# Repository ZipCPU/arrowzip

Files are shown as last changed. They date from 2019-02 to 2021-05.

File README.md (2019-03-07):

## ArrowZip

This design is currently a work in progress.  The goal is to place a
[ZipCPU](http://zipcpu.com/about/zipcpu.html) onto a
[$30 Max1000 FPGA](http://zipcpu.com/blog/2017/12/16/max1k.html),
as sold by [Arrow](https://www.arrow.com) and
[Trenz Electronics](https://www.trenz-electronic.de).

If all goes well, this will include access to ...

- The on-board SDRAM.  This includes not only the
  [Verilog code](rtl/arrowzip/wbsdram.v) to access this SDRAM, but also a
  [simulation component](sim/verilated/sdramsim.cpp) for the SDRAM, as well
  as an [AutoFPGA](https://github.com/ZipCPU/autofpga)
  [script](auto-data/sdram.txt)
  to add (or remove) the SDRAM from this build.

  This capability now works.

- A dual-I/O flash, running in both XIP (Execute in Place) mode as well as
  a debug-bus configuration override.  As with the SDRAM, this will include
  not only the [Verilog code](rtl/arrowzip/dualflexpress.v), but also a
  simulation component and an [AutoFPGA](https://github.com/ZipCPU/autofpga)
  [script](auto-data/flexpress.txt)
  to add (or remove) the flash from this build.

  The [flash controller](rtl/arrowzip/dualflexpress.v) now works as well.

- The on-board MEMS motion sensor.

  This last piece remains a work in progress.

## 20190307 Update: The SDRAM is working

1. The design now builds and runs, both in simulation and on hardware, using
   the [flash controller](rtl/arrowzip/dualflexpress.v).

2. The [SDRAM controller](rtl/arrowzip/wbsdram.v) now passes a [memory
   test](sw/board/memtest.c), and should be ready to use.

3. The I/O drivers are currently Intel generated IP.  These still need to
   be replaced by references to the actual underlying drivers.  However, if you
   create the I/O drivers yourself, then you can run the design as is.

## To run this design ...

First, install Quartus, Verilator, and the
[ZipCPU toolchain](https://zipcpu.com/zipcpu/2018/01/31/cpu-build.html).

To run from simulation, build the design (make) and then cd into
the [sim/verilated](sim/verilated/).  Type "main_tb" to start the simulator.
"main_tb -d" will start creating a VCD file at the same time.  "main ../../sw/board/cputest" will load the CPU test into the [ZipCPU](https://zipcpu.com/about/zipcpu.html).  While running the simulation, you can telnet into "localhost 6956" to interact with the serial port of the design.  You can also use the [wbregs program](sw/host/wbregs.cpp) to read and set various addresses peripheral and otehrwise within the design.

For example, "wbregs stopwatch 1" will start the stopwatch capability. "wbregs timer 0x130" will start a timer counting down from one minute and thirty seconds.  "wbregs clock 0x210837" will set the RTC clock time to 9:08:37 PM.

To run the design on the device itself, build the design and then load it into
the device (see the vendor's instructions) and then run "netuart" from the
[sw/host](sw/host) directory.  You may need to give it the name of your serial
port, as in "netuart /dev/ttyUSB0".  (Both the simulator and [netuart](sw/host/netuart.cpp) use the same network port, so you'll only be able to run one of these at a time.)  You should then be able to use the [wbregs](sw/host/wbregs.cpp) program to interact with the various registers within the design.  To load the [cputest](sw/board/cputest.c), run "[zipload](sw/host/zipload.c) -r [../board/cputest](sw/board/cputest.c)" from the [sw/host](sw/host) directory.  You should then see a series of tests results posted on the serial port.

To reconfigure the design, such as to add or remove device or to adjust the amount of block RAM, you'll need to adjust the files in the [auto-data](auto-data) directory and re-run [AutoFPGA](https://github.com/ZipCPU/autofpga).

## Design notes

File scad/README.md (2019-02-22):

## SCAD Drawings

This directory contains such SCAD drawings as can be used to create a case
using [OpenSCAD](http://www.openscad.org).  There's also an [STL](arrowzip.stl)
file, also generated by [OpenSCAD](http://www.openscad.org), that you can use
with your printer if you don't want to generate it yourself using
[OpenSCAD](http://www.openscad.org).

Use them at your own risk, as my first version tore the buttons off of the side
of my board.

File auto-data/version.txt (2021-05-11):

################################################################################
##
## Filename: 	version.txt
## {{{
## Project:	ArrowZip, a demonstration of the Arrow MAX1000 FPGA board
##
## Purpose:	
##
## Creator:	Dan Gisselquist, Ph.D.
##		Gisselquist Technology, LLC
##
################################################################################
## }}}
## Copyright (C) 2017-2021, Gisselquist Technology, LLC
## {{{
## This program is free software (firmware): you can redistribute it and/or
## modify it under the terms of  the GNU General Public License as published
## by the Free Software Foundation, either version 3 of the License, or (at
## your option) any later version.
##
## This program is distributed in the hope that it will be useful, but WITHOUT
## ANY WARRANTY; without even the implied warranty of MERCHANTIBILITY or
## FITNESS FOR A PARTICULAR PURPOSE.  See the GNU General Public License
## for more details.
##
## You should have received a copy of the GNU General Public License along
## with this program.  (It's in the $(ROOT)/doc directory.  Run make with no
## target there if the PDF file isn't present.)  If not, see
## <http://www.gnu.org/licenses/> for a copy.
## }}}
## License:	GPL, v3, as defined and found on www.gnu.org,
## {{{
##		http://www.gnu.org/licenses/gpl.html
##
################################################################################
##
## }}}
@PREFIX=version
@DEVID=VERSION
@NADDR=1
@SLAVE.TYPE=SINGLE
@SLAVE.BUS=wb
@MAIN.DEFNS=
`include "builddate.v"
@MAIN.INSERT=
	assign	@$(PREFIX)_data = `DATESTAMP;
	assign	@$(PREFIX)_ack = wb_stb && @$(PREFIX)_sel;
	assign	@$(PREFIX)_stall = 1'b0;
@REGS.N=1
@REGS.0= 0 R_@$(DEVID) @$(DEVID)
@BDEF.IONAME=_@$(PREFIX)
@BDEF.IOTYPE=unsigned
@BDEF.OSDEF=_BOARD_HAS_@$(DEVID)
@BDEF.IOTYPE=static volatile @$BDEF.IOTYPE *const @$BDEF.IONAME = &((@$BDEF.IOTYPE *)@$[0x%08x](REGBASE));
##
##
##
@PREFIX=buildtime
@DEVID=BUILDTIME
@NADDR=1
@SLAVE.TYPE=SINGLE
@SLAVE.BUS=wb
@MAIN.DEFNS=
// BUILDTIME doesnt need to include builddate.v a second time
// `include "builddate.v"
@MAIN.INSERT=
`ifdef	VERILATOR
	assign	@$(PREFIX)_data = `BUILDTIME ^ 32'h8000_0000;
`else
	assign	@$(PREFIX)_data = `BUILDTIME;
`endif
	assign	@$(PREFIX)_ack = wb_stb && @$(PREFIX)_sel;
	assign	@$(PREFIX)_stall = 1'b0;
@REGS.N=1
@REGS.0= 0 R_@$(DEVID) @$(DEVID)
@BDEF.IONAME=_@$(PREFIX)
@BDEF.IOTYPE=unsigned
@BDEF.OSDEF=_BOARD_HAS_@$(DEVID)
@BDEF.IOTYPE=static volatile @$BDEF.IOTYPE *const @$BDEF.IONAME = &((@$.BDEF.IOTYPE *)@$[0x%08x](REGBASE));

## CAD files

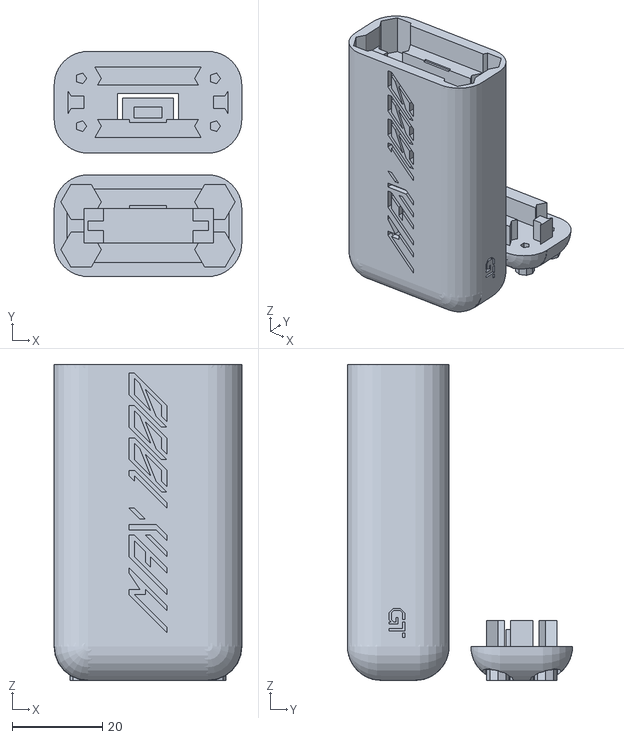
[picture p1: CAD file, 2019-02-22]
scad/arrowzip.stl
41.7 x 50.0 x 70.2

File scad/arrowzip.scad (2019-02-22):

include <GT.scad>
include <zipcpu.scad>
include <max1klogo.scad>
	
module	arrowcase(cap = 0) {
	//
	// Measurements
	raw_board_thickness =  1.3;
	bx_component_thickness = 2*(3.2-raw_board_thickness)
					+raw_board_thickness + 2.5;
	raw_board_width     = 26.0;
	raw_board_length    = 62.0;
	//
	bx_board_thickness     = raw_board_thickness + 0.7;
	bx_board_width         = raw_board_width  + 0.7;
	bx_board_length        = raw_board_length + 0.7;
	bx_clear_board_edge    =  7.0;
	//
	usb_height = 4.2-raw_board_thickness + 0.5;
	usb_width  = 7.6  + 0.5;
	usb_depth  = 5.25 + 0.5;

	////////////////////////////
	//
	// USB plug dimensions
	//
	// This isn't the actual metal USB size.  That's fixed by the
	// standard.  This is the size of the plastic that surrounds
	// that plug.
	//
	// First USB plug dimensions
	// usb_plug_width = 10.1 + 1.5;
	usb_plug_height=  6.8 + 1.5;

	// Second plug dimensions
	usb_plug_width = 11.8 + 1.5;
	// usb_plug_height=  5.9 + 1.5;

	// Second plug dimensions
	// usb_plug_width = 9.0 + 1.5;
	usb_plug_height=  7.6 + 1.5;

	////////////
	//
	standoff_height       = 10;
	standoff_flat_to_flat = 4.5;
	//
	screw_diameter= 2.5;
	screw_length  = 4.1;
	screw_head_diameter = 5.5+0.6;
	screw_head_height   = 1.5;
	//
	// Derived measurements
	// standoff_radius = standoff_flat_to_flat / sqrt(2.0);
	// Because this is an "inside" standoff, it the radius is measured
	// to the flats, not the corners
	standoff_radius = standoff_flat_to_flat;
	//
	// My choices
	tolerance = 0.1;
	bx_edge_thickness = standoff_flat_to_flat + 3;
	bx_component_width = bx_board_width-bx_clear_board_edge;
	chamber_height = bx_component_thickness;
	exwidth  = bx_board_width    + 2*bx_edge_thickness;
	exlength = bx_board_length   + 2*bx_edge_thickness;
	exheight = chamber_height    + 2*bx_edge_thickness;
	
	inx = bx_edge_thickness + tolerance/2;
	iny = bx_edge_thickness + tolerance/2;
	inz = bx_edge_thickness;
	bottom_of_board = inz + chamber_height/2-bx_board_thickness/2;
	
	module raw_case() {
		cube([exwidth, exlength, exheight]);
	}
	
	module	rounded_case() {
		rad = bx_edge_thickness;
		tol = tolerance;
		union() {
			difference() {
				raw_case();
				//
				translate([-tol,-tol,-tol])
					cube([rad+tolerance,exlength+2*tol,
						rad+tol]);
				translate([exwidth-rad,-tolerance,-tolerance])
					cube([rad+tol,exlength+2*tol,
						rad+tol]);
				translate([-tolerance,exlength-rad,-tol])
					cube([exwidth+2*tol,rad+tol,
						rad+tol]);
				translate([-tol,exlength-rad,-tol])
					cube([rad+tol,rad+tol,
						exheight+2*tol]);
				translate([exwidth-rad,exlength-rad,-tol])
					cube([rad+tol,rad+tol,
						exheight+2*tol]);
				// Top side
				translate([-tol,-tol,exheight-rad])
					cube([rad+tol,exlength+2*tol,
						rad+2*tol]);
				translate([exwidth-rad,-tol,exheight-rad])
					cube([rad+tol,exlength+2*tol,
						rad+2*tol]);
				translate([-tol,exlength-rad,exheight-rad])
					cube([exwidth+2*tol,rad+2*tol,
						rad+2*tol]);
				// Front side
				translate([-tol,-tol,-tol])
					cube([exwidth+2*tol,rad+tol,
						rad+tol]);
				translate([-tol,-tol,exheight-rad])
					cube([exwidth+2*tol,rad+tol,
						rad+tol]);
				translate([-tol,-tol,-tol])
					cube([rad+tol,rad+tol,
						exheight+2*tol]);
				translate([exwidth-rad,-tol,-tol])
					cube([rad+tol,rad+tol,
						exheight+2*tol]);
			}
	
			// The corners
			translate([rad,exlength-rad,rad])
				sphere(rad);
			translate([exwidth-rad,exlength-rad,rad])
				sphere(rad);
			translate([rad,exlength-rad,exheight-rad])
				sphere(rad);
			translate([exwidth-rad,exlength-rad,exheight-rad])
				sphere(rad);
			// Front corners
			translate([rad,rad,rad])
				sphere(rad);
			translate([exwidth-rad,rad,rad])
				sphere(rad);
			translate([rad,rad,exheight-rad])
				sphere(rad);
			translate([exwidth-rad,rad,exheight-rad])
				sphere(rad);
	
	
	
			// The sides
			translate([rad,rad,rad]) rotate([-90,0,0])
				cylinder(h=exlength-2*rad,r=rad);
			translate([exwidth-rad,rad,rad]) rotate([-90,0,0])
				cylinder(h=exlength-2*rad,r=rad);
			translate([rad,exlength-rad,rad]) rotate([0,90,0])
				cylinder(h=exwidth-2*rad,r=rad);
			// And on the top
			translate([rad,rad,exheight-rad]) rotate([-90,0,0])
				cylinder(h=exlength-2*rad,r=rad);
			translate([exwidth-rad,rad,exheight-rad]) rotate([-90,0,0])
				cylinder(h=exlength-2*rad,r=rad);
			translate([rad,exlength-rad,exheight-rad]) rotate([0,90,0])
				cylinder(h=exwidth-2*rad,r=rad);
			// Vertical supports
			translate([rad,exlength-rad,rad])
				cylinder(h=exheight-2*rad,r=rad);
			translate([exwidth-rad,exlength-rad,rad])
				cylinder(h=exheight-2*rad,r=rad);
			// The front face
			translate([rad,rad,rad]) rotate([0,90,0])
				cylinder(h=exwidth-2*rad,r=rad);
			translate([rad,rad,exheight-rad]) rotate([0,90,0])
				cylinder(h=exwidth-2*rad,r=rad);
			translate([exwidth-rad,rad,rad])
				cylinder(h=exheight-2*rad,r=rad);
			translate([rad,rad,rad])
				cylinder(h=exheight-2*rad,r=rad);
		}
	}
	
	module	inside_chamber() {
		bw = bx_board_width;
		ch = chamber_height;
		cw = bx_component_width;
		// tol=tolerance;
		tol=0.1;
		spare_end_width = 22;
		btnw = 1;

		union() {
			// Room for the bare board
			//
			translate([inx-tol/2, iny-tol/2,
					inz+(ch-bx_board_thickness-tol)/2])
				cube([bx_board_width+tol,
					bx_board_length+tol,
					bx_board_thickness+tol]);
	
			// Room for the electronics around the board
			translate([inx+(bw-cw-tol)/2, iny-tol/2+bx_clear_board_edge/2,
					inz-tol/2])
				cube([cw + tol,
					bx_board_length-bx_clear_board_edge/2+tol,
					chamber_height+tol]);

			// Room for the electronics near the end
			translate([inx-btnw+tol/2, iny-tol/2,
					inz-tol/2])
				cube([bx_board_width+btnw*2+tol,
					spare_end_width+tol,
					chamber_height+tol]);
		}
	}
	
	module	board() {
		color("green") {
			translate([inx, iny,
				bottom_of_board])
				cube([bx_board_width, bx_board_length, bx_board_thickness]);
		}
	}
	
	module	embossGT() {
		s = 0.25;
		depth = 1.5;
		union() {
			translate([exwidth+gtlogo_h*s/2-depth,
				exlength-2*s*gtlogo_l-bx_edge_thickness-1.5,
				gtlogo_l*s/2+bx_edge_thickness]) {
			rotate([0,0,90]) { rotate([90,0,0]) { scale([s,s,s]) {
				translate([-gtlogo_w*s,-gtlogo_l*s,-gtlogo_h*s]);
						GTlogo(); }
			}}}
	
			translate([-gtlogo_h*s/2+depth,
				gtlogo_l*s+bx_edge_thickness + 3,
				gtlogo_w*s/2+bx_edge_thickness]) {
			rotate([0,0,-90]) { rotate([90,0,0]) { scale([s,s,s]) {
	
				translate([-gtlogo_w*s,-gtlogo_l*s,-gtlogo_h*s])
					GTlogo(); }
			}}}
		}
	}
	
	module	embossZip() {
		s = 1.0;
		depth = 1.5;
		union() {
			translate([exwidth/2,
				exlength/2,
				exheight+zlogoh/2-depth])
			{
			rotate([0,0,90]) scale([s,s,1]) {
				translate([-zlogow/2,(zlogob-zlogol)/2,-zlogoh/2])
						zipcpulogo(); }
			}
		}
	}

	module	embossMax1k(depth) {
		s = 1.2;
		sw = s * max1klogo_w;
		sl = s * max1klogo_l;
		sh = max1klogo_l;
		depth = 1.5;
		union() {
			translate([exwidth/2,
				exlength/2,
				-max1klogo_h/2+depth])
			{
			rotate([0,180,90]) scale([s,s,1]) {
				translate([-max1klogo_w/2,-max1klogo_l/2,-max1klogo_h/2])
						max1klogo(); }
			}
		}
	}

	module	standoff_holes() {
		tol = tolerance;
		rad = standoff_flat_to_flat;
		shp = standoff_height+tol;
		// Inset = (distance from edge) + rad/2
		// Inset = 2mm + rad
		inset = 1.5+rad;
		translate([inset, iny+standoff_height+tol, inset])
			rotate([90,0,0])
				cylinder(h=shp,r=standoff_radius,$fn=6);
		translate([exwidth-inset, iny+standoff_height+tol, inset])
			rotate([90,0,0])
				cylinder(h=shp,r=standoff_radius,$fn=6);
		translate([inset, iny+standoff_height+tol, exheight-inset])
			rotate([90,0,0])
				cylinder(h=shp,r=standoff_radius,$fn=6);
		translate([exwidth-inset, iny+standoff_height+tol,	
				 exheight-inset])
			rotate([90,0,0])
				cylinder(h=shp,r=standoff_radius,$fn=6);
	
		// clean things up a ... touch
		/*
		translate([rad, iny-tol, rad*3/4])
			cube([exwidth-2*rad,standoff_height+tol,
				exheight-2*rad*3/4]);
		*/
		/*
		translate([rad, iny-tol, rad])
			cube([exwidth-2*rad,standoff_height+tol,
				exheight-rad*2.0]);
		*/
	}
	
	module	screw_holes() {
		tol = tolerance;
		rad = standoff_flat_to_flat;
		inset = 1.5+rad;
		srad= (screw_diameter)/2;
		sch= iny+standoff_height/2;
		headr = (screw_head_diameter+0.8+tol)/2;
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

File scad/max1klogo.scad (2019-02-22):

module	max1klogo() {
	module	max1k() {
		linear_extrude(height=5) {
			union() {
				// M
				polygon(points=[
					[0,0],
					[1,0],
					[7,6],
					[7,4],
					[8,4],
					[4,0],
					[5,0],
					[12,7],
					[11,7],
					[8,5],
					[8,7],
					[7,7] ]);
				// A
				polygon(points=[
					[7,0],
					[8,0],
					[14,6],
					[17,6],
					[15,4],
					[13,4],
					[12,3],
					[14,3],
					[11,0],
					[12,0],
					[18,6],
					[18,7],
					[14,7],
					]);
				// X
				polygon(points=[
					[14,0],
					[15,0],
					[18,3],
					[18,4] ]);
				polygon(points=[
					[17,0],
					[18,0],
					[20,2],
					[20,7],
					[19,7],
					[19,2] ]);
				polygon(points=[
					[21,4],
					[23,6],
					[23,7],
					[21,5],
					 ]);
			}
		}
	}

	module	max1k1k() {
		linear_extrude(height=5) {
			union() {
				// 1
				polygon(points=[
					[0,0],
					[1,0],
					[7,6],
					[7,7],
					[6,7],
					[5,6],
					[6,6] ]);
				// 0
				translate([0,0,0]) { polygon(points=[
					[3,1],
					[3,0],
					[9,6],
					[12,6],
					[11,5],
					[6,3],
					[5,2],
					[10,4],
					[7,1],
					[5,1],
					[4,0],
					[7,0],
					[13,6],
					[13,7],
					[9,7],
					]); }
				// 0
				translate([6,0,0]) { polygon(points=[
					[3,1], [3,0], [9,6], [12,6], [11,5],
					[6,3], [5,2], [10,4], [7,1], [5,1],
					[4,0], [7,0], [13,6], [13,7], [9,7]
					]); }
				// 0
				translate([12,0,0]) { polygon(points=[
					[3,1], [3,0], [9,6], [12,6], [11,5],
					[6,3], [5,2], [10,4], [7,1], [5,1],
					[4,0], [7,0], [13,6], [13,7], [9,7]
					]); }
			}
		}
	}

	translate([0,0,0]) {
		max1k();

		translate([23,0,0]) {
			max1k1k();
		}
	}
}

max1klogo_w = 47;
max1klogo_l = 7;
max1klogo_h = 5;

module	max1kshell() {
	difference() {
		w = 2;
		translate([-w/2,-w/2,-w+0.2]) {
			cube([max1klogo_w+w, max1klogo_l+w, max1klogo_h]);
		}
		cube([max1klogo_w, max1klogo_l, max1klogo_h]);
	}
}

// max1kshell();
// max1klogo();

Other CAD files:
scad/GT.scad
scad/zipcpu.scad

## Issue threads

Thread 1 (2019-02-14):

great project

NeuerUser, 2019-02-14:
I also got this board to learn about FPGA. It would be too great to also have the ZipCPU on this board.
But it looks very daunting to me. Do you think you can get it working?

Cheers

Michael

ZipCPU, 2019-02-26:
Yes.

Large portions of the design are working already, and should be checked in.

I'm still testing the flash memory using my new flash driver, but haven't (yet) gotten to either the SDRAM or the SPI-based accelerometer..  Those remain on my to-do list.  The CPU should be able to work as is though.

Still need to figure out how to package the various Altera/Intel specific primitives.  Those are likely to slow you down.

NeuerUser, 2019-02-27:
Hi Dan

That sounds like pretty good news. I would love to play around with it. Looking forward to anything you release.

Thanks again for your hard work!

Michael

ZipCPU, 2019-03-04:
I threw in the two altera primitives, so feel free to try out the project with them.

I still don't have the SDRAM memory working (yet), but the CPU should be in working order.

Dan

NeuerUser, 2019-03-04:
Thanks. That helps a lot.
SDRAM would be nice, but it  would alrady be great to get it working even without.

ZipCPU, 2019-03-04:
The good news is that I already have the [SDRAM controller](https://github.com/ZipCPU/xulalx25soc/blob/master/rtl/wbsdram.v), I just need to port it from [another one of my designs](https://github.com/ZipCPU/xulalx25soc) to this one and get it up and running.

NeuerUser, 2019-03-05:
That's very nice, indeed. That would mean it could be a fully featured Soc .)

ZipCPU, 2019-03-06:
The ZipCPU now works on this board.  I still need to get the SDRAM and MEMs sensor running, but the CPU itself is running.

To use, load the design onto your board, and then run (from sw/host) "zipload -r ../board/cputest".  While it is loading, telnet into port 6956 (one greater than FPGAPORT in sw/host/port.h).  Once the zipload program has loaded the CPU test program into the flash, you'll see a report in your telnet window.

Closed 2019-03-06.

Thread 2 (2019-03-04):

Error (12006): Node instance "dspi_ddr_csn" instantiates undefined entity "altoddr".

NeuerUser, 2019-03-04:
I am still very new to FPGAs and your AutoMake powered designs in special. So, please bear with me.

When I try to import this design into quartus, I get the following errors on design analysis:

~~~~
Error (12006): Node instance "dspi_ddr_csn" instantiates undefined entity "altoddr". Ensure that required library paths are specified correctly, define the specified entity, or change the instantiation. If this entity represents Intel FPGA or third-party IP, generate the synthesis files for the IP.
Error (12006): Node instance "dspi_ddr_sck" instantiates undefined entity "altoddr". Ensure that required library paths are specified correctly, define the specified entity, or change the instantiation. If this entity represents Intel FPGA or third-party IP, generate the synthesis files for the IP.
Error (12006): Node instance "dspi_d0" instantiates undefined entity "addrio". Ensure that required library paths are specified correctly, define the specified entity, or change the instantiation. If this entity represents Intel FPGA or third-party IP, generate the synthesis files for the IP.
Error (12006): Node instance "dspi_d1" instantiates undefined entity "addrio". Ensure that required library paths are specified correctly, define the specified entity, or change the instantiation. If this entity represents Intel FPGA or third-party IP, generate the synthesis files for the IP.
~~~~

This seems to emenate from the toplevel.v file, where there are the following instatiations:

~~~~
	// Wires for setting up the QSPI flash wishbone peripheral
	//
	//
	// QSPI)BMOD, Dual SPI bus mode, Bus modes are:
	//	0?	Normal serial mode, one bit in one bit out
	//	10	Dual SPI mode, going out
	//	11	Dual SPI mode coming from the device (read mode)
	altoddr dspi_ddr_csn(
		.outclock(s_clk),
		.din({(2){ w_dspi_cs_n}}),
		.pad_out(o_dspi_cs_n));
	altoddr dspi_ddr_sck( .outclock(s_clk),
		// .din({ !w_dspi_sck, 1'b1 }),
		.din({(2){w_dspi_sck}}),
		.pad_out(o_dspi_sck));
	addrio	dspi_d0(.inclock(s_clk), .outclock(s_clk),
			.dout({dspi_datp[0], dspi_datn[0]}),
			.din({(2){o_dspi_dat[0]}}),
			.pad_io(io_dspi_dat[0]),
			.oe(!dspi_bmod[0]));
	addrio	dspi_d1(.inclock(s_clk), .outclock(s_clk),
			.dout({dspi_datp[1], dspi_datn[1]}),
			.din({(2){o_dspi_dat[1]}}),
			.pad_io(io_dspi_dat[1]),
			.oe((dspi_bmod == 2'b10)?1'b1:1'b0));
~~~~

What am I missing here? Where do I find these modules?

Thanks!

ZipCPU, 2019-03-04:
There are actually three modules you need.  One of them is addrio, another is altoddr, the third appears to be in the repository although I'm not (yet) certain if it is usable or not.  addrio.v and altoddr.v are both files generated by Quartus for handling the high speed I/O used by the flash controller.  I just placed them into the rtl/common directory.  When Quartus builds them, they come with a bunch of other baggage that (hopefully) you won't need.  Feel free to try them out and see how far you can get with them, while I see if I can't remove them somehow.

Incidentally, the goal is to be able to build this project with Yosys and ... those Quartus generated files are somewhat keeping me from this.

Dan

NeuerUser, 2019-03-05:
Hi Dan

Thanks for your help. Unfortunately, I still wasn't able to get the design compiled. I guess that's mostly because of my missing knowledge. Here is what I experienced:

1. There were error messages within genpll.v about the parameters "altpll_component.clk1_divide_by", "altpll_component.clk1_duty_cycle", "altpll_component.clk1_multiply_by" and "altpll_component.clk1_phase_shift" not being formal parameters. I could work around this by commenting out these options.
2. Then the compilation went one step further, this time complaining that the module "altera_gpio_lite" is missing. I got the impression that this is needed for addrio and altoddr. So, I took a deeper look at these two and recreated them with the altera IP generator.
3. While this worked finally, I still get errors now about port inputs not being proper clock sources. These ports seem to be ports from underlying components of the altera_gpio_lite. They look like this:

~~~~
Error (16080): Input port CLKHI of "altoddr:dspi_ddr_sck|altera_gpio_lite:altoddr_inst|altgpio_one_bit:gpio_one_bit.i_loop[0].altgpio_bit_i|out_path_ddr.fr_out_data_ddio"  must be connected with a proper clock source.
Error (16081): Input port CLKLO of "altoddr:dspi_ddr_sck|altera_gpio_lite:altoddr_inst|altgpio_one_bit:gpio_one_bit.i_loop[0].altgpio_bit_i|out_path_ddr.fr_out_data_ddio"  must be connected with a proper clock source..
Error (16082): Input port MUXSEL of "altoddr:dspi_ddr_sck|altera_gpio_lite:altoddr_inst|altgpio_one_bit:gpio_one_bit.i_loop[0].altgpio_bit_i|out_path_ddr.fr_out_data_ddio"  must be connected with a proper clock source..
Error (16080): Input port CLKHI of "altoddr:dspi_ddr_csn|altera_gpio_lite:altoddr_inst|altgpio_one_bit:gpio_one_bit.i_loop[0].altgpio_bit_i|out_path_ddr.fr_out_data_ddio"  must be connected with a proper clock source.
Error (16081): Input port CLKLO of "altoddr:dspi_ddr_csn|altera_gpio_lite:altoddr_inst|altgpio_one_bit:gpio_one_bit.i_loop[0].altgpio_bit_i|out_path_ddr.fr_out_data_ddio"  must be connected with a proper clock source..
Error (16082): Input port MUXSEL of "altoddr:dspi_ddr_csn|altera_gpio_lite:altoddr_inst|altgpio_one_bit:gpio_one_bit.i_loop[0].altgpio_bit_i|out_path_ddr.fr_out_data_ddio"  must be connected with a proper clock source..
Error (16080): Input port CLKHI of "addrio:dspi_d1|altera_gpio_lite:addrio_inst|altgpio_one_bit:gpio_one_bit.i_loop[0].altgpio_bit_i|out_path_ddr.fr_out_data_ddio"  must be connected with a proper clock source.
Error (16081): Input port CLKLO of "addrio:dspi_d1|altera_gpio_lite:addrio_inst|altgpio_one_bit:gpio_one_bit.i_loop[0].altgpio_bit_i|out_path_ddr.fr_out_data_ddio"  must be connected with a proper clock source..
Error (16082): Input port MUXSEL of "addrio:dspi_d1|altera_gpio_lite:addrio_inst|altgpio_one_bit:gpio_one_bit.i_loop[0].altgpio_bit_i|out_path_ddr.fr_out_data_ddio"  must be connected with a proper clock source..
Error (16080): Input port CLKHI of "addrio:dspi_d0|altera_gpio_lite:addrio_inst|altgpio_one_bit:gpio_one_bit.i_loop[0].altgpio_bit_i|out_path_ddr.fr_out_data_ddio"  must be connected with a proper clock source.
Error (16081): Input port CLKLO of "addrio:dspi_d0|altera_gpio_lite:addrio_inst|altgpio_one_bit:gpio_one_bit.i_loop[0].altgpio_bit_i|out_path_ddr.fr_out_data_ddio"  must be connected with a proper clock source..
Error (16082): Input port MUXSEL of "addrio:dspi_d0|altera_gpio_lite:addrio_inst|altgpio_one_bit:gpio_one_bit.i_loop[0].altgpio_bit_i|out_path_ddr.fr_out_data_ddio"  must be connected with a proper clock source..
~~~~

I guess, I am currently at the end of my understanding. Do you have any idea what is missing?

NeuerUser, 2019-03-05:
small update:

I followed the signals from the error messages up to the toplevel. In the end the messages seem to complain (if I understand it correctly), that 's_clk' is not a proper clock source for the altera_gpio_lite module and its submodules.

I will see if it helps if I recreate the genpll module.

NeuerUser, 2019-03-05:
Doesn't help. If I recreate the genpll module, I am back to the original error messages complaining about the formal parameters:
~~~~
Error (10130): Verilog HDL error at genpll.v(101): parameter "clk1_divide_by" is not a formal parameter of instantiated module
Error (10130): Verilog HDL error at genpll.v(102): parameter "clk1_duty_cycle" is not a formal parameter of instantiated module
Error (10130): Verilog HDL error at genpll.v(103): parameter "clk1_multiply_by" is not a formal parameter of instantiated module
Error (10130): Verilog HDL error at genpll.v(104): parameter "clk1_phase_shift" is not a formal parameter of instantiated module
Error (12152): Can't elaborate user hierarchy "genpll:genclk"
~~~~
Which I find strange, as Quartus itself has generated the file. So, why should it then complain about it... Very strange...

NeuerUser, 2019-03-05:
OK, SUCCESS! I found the culprit. There was a (maybe leftover) file called "altpll.v", which seemed to interfere. As soon, as I removed it from the project, compilation went through (and I could also keep the above mentioned parameters).
I don't think that the error messages I got were very helpful. The only thing they told me were that it had something to do with a clock source.

Ok, now I will see if I can get it running on the board and how to interact with it via the debug interface.

NeuerUser, 2019-03-05:
btw:
Flow Status	Successful - Tue Mar  5 11:31:36 2019
Quartus Prime Version	18.1.0 Build 625 09/12/2018 SJ Lite Edition
Revision Name	ArrowZip
Top-level Entity Name	toplevel
Family	MAX 10
Device	10M08SAU169C8G
Timing Models	Final
Total logic elements	4,987 / 8,064 ( 62 % )
Total registers	2717
Total pins	16 / 130 ( 12 % )
Total virtual pins	0
Total memory bits	297,984 / 387,072 ( 77 % )
Embedded Multiplier 9-bit elements	16 / 48 ( 33 % )
Total PLLs	1 / 1 ( 100 % )
UFM blocks	0 / 1 ( 0 % )
ADC blocks	0 / 1 ( 0 % )

NeuerUser, 2019-03-05:
closing this issue as it is solved now
(other open points in new issues)

ZipCPU, 2019-03-05:
Thanks for closing the issue, although I will note that the problem still isn't really solved.  My goal is that you should be able to build this design without needing to use the Altera IP generator.

Keep your eyes peeled, I might be able to offer that in the near future.

NeuerUser, 2019-03-05:
That would be great. I am not really a fan of Altera's IP generator. :+1:

Closed 2019-03-05.

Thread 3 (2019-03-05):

Where to continue?

NeuerUser, 2019-03-05:
Hi Dan

So, I have the design running on the MAX1000 now. I am, however, not sure if it works correctly, as I don't know the whole thing at all. Here are my observations so far:

- board consumes 134mA
- LEDs are running knightrider
- wbregs works when reading, but not when writing, it seems:
~~~~
 $./wbregs BUILDTIME
00400000 (BUILDTIME) : [.!5(] 00213528
 $./wbregs VERSION
00400014 ( VERSION) : [....] 20190219
$ ./wbregs TIMER
00500044 (   TIMER) : [....] 00000000
$ ./wbregs TIMER 0x12345678
00500044 (   TIMER)-> 12345678
$ ./wbregs TIMER
00500044 (   TIMER) : [....] 00000000
$ ./wbregs FLASH
00800000 (   FLASH) : [....] 00000000
$ ./wbregs RAM
00600000 (     RAM) : [....] 00000000
$ ./wbregs ALARM
0050004c (   ALARM) : [....] 00000000
$ ./wbregs BUSTIMER
00500000 (BUSTIMER) : [....] 00000000
$ ./wbregs BUSTIMER 0x01
00500000 (BUSTIMER)-> 00000001
$ ./wbregs BUSTIMER
00500000 (BUSTIMER) : [....] 00000000
~~~~
- zipload complains about wrong board
~~~~
$ ./zipload ../board/cputest
Could not communicate with board (invalid version)
~~~~
- zipdbg shows buserror:
~~~~
Peripherals                   CPU State: 0x00000613 Supervisor mode
>PIC > 0x00000000<   WDT : 0x00000000    WBUS: 0x00000000    PIC2: 0x00000000
 TMRA: 0x00000000    TMRB: 0x00000000    TMRC: 0x00000000    JIF : 0x00000000
 MTSK: 0x00000000    MOST: 0x00000000    MPST: 0x00000000    MICT: 0x00000000

Supervisor Registers
 sR0 : 0x00000000    sR1 : 0x00000000    sR2 : 0x00000000    sR3 : 0x00000000
 sR4 : 0x00000000    sR5 : 0x00000000    sR6 : 0x00000000    sR7 : 0x00000000
 sR8 : 0x00000000    sR9 : 0x00000000    sR10: 0x00000000    sR11: 0x00000000
 sR12: 0x00000000    sSP : 0x00000000    sCC :           Z   sPC : 0x0060000c
User Registers
 uR0 : 0x00000000    uR1 : 0x00000000    uR2 : 0x00000000    uR3 : 0x00000000
 uR4 : 0x00000000    uR5 : 0x00000000    uR6 : 0x00000000    uR7 : 0x00000000
 uR8 : 0x00000000    uR9 : 0x00000000    uR10: 0x00000000    uR11: 0x00000000
 uR12: 0x00000000    uSP : 0x00000000    uCC :               uPC : 0x00000000

                                                     >00000000 (Bus Err)
 0x00600014 0x00000000  SUB        $0,R0              00000004 (Bus Err)
 0x00600010 0x00000000  SUB        $0,R0              00000008 (Bus Err)
>0x0060000c 0x00000000  SUB        $0,R0              0000000c (Bus Err)
 0x00600008 0x00000000  SUB        $0,R0              00000010 (Bus Err)
~~~~

Any idea, how best to go forward? I still don't know this well enough...

ZipCPU, 2019-03-05:
Looks like your software components are out of synch with the rest of the design.  Try running "make" from the root directory again.  That should fix both the TIMER and the VERSION issue.  Once the VERSION issue is fixed, zipload should work again.

As for the timer, try writing to the "BUSTIMER" first.  This is a basic count-down timer that will accept any value.  If you wait too long before querying it, it will set an interrupt and then read zero again.  You can check for the interrupt by reading from the programmable interrupt controller, "PIC".  Check out the ZipCPU spec for the documentation on how both the BUSTIMER and the PIC are supposed to work.

The "TIMER" is a BCD based seconds timer.  Hence, if you write 0x0130 to it, it should count down a minute and a half before setting the RTC interrupt in the PIC.  This is also a good test of whether the design is up and running, although I'm not sure I'd ever try writing 0x12345678 to it ;)

NeuerUser, 2019-03-05:
Good, a new make helped, indeed. Still not all working, but definitely looking better!!!

- version and buildtime is uptodate now:
~~~~
$ ./wbregs VERSION
00400014 ( VERSION) : [....] 20190305
$ ./wbregs BUILDTIME
00400000 (BUILDTIME) : [..P#] 00145023
~~~~
- BUSTIMER seems to be able to count down pretty fast:
~~~~
$ ./wbregs BUSTIMER
00500000 (BUSTIMER) : [....] 00000000
$ ./wbregs BUSTIMER 0x12345678
00500000 (BUSTIMER)-> 12345678
$ ./wbregs BUSTIMER
00500000 (BUSTIMER) : [...H] 0b04f948
$ ./wbregs BUSTIMER
00500000 (BUSTIMER) : [....] 040111b8
$ ./wbregs BUSTIMER
00500000 (BUSTIMER) : [....] 00000000
~~~~
- TIMER does somehow not really count down, though
~~~~
$ ./wbregs TIMER
00500044 (   TIMER) : [....] 00000000
 ./wbregs TIMER 0x0130
00500044 (   TIMER)-> 00000130
$ ./wbregs TIMER
00500044 (   TIMER) : [...0] 01000130
$ ./wbregs TIMER
00500044 (   TIMER) : [...0] 01000130
~~~~
- zipload complains about the memory
~~~~
$ ./zipload ../board/cputest
Halting the CPU
Loading: ../board/cputest
No such memory on board: 0x00008000 - 0000b5c0
~~~~
- zipdbg still report a Bus Error.

NeuerUser, 2019-03-05:
btw, what also works very nicely is the SPIO register :) Can control the LEDs nicely.

Major problem seems to be the memory. That is probably the RAM, I guess.

ZipCPU, 2019-03-05:
I'm also expecting problems with the flash controller.  I've got a brand new flash controller, and ... it's still going through some growing pains.

NeuerUser, 2019-03-05:
I tried the dumpflash program. It reported:
~~~~
$ ./dumpflash
Before starting, nread = 0
VERSION: 20190305

READ-COMPLETE
The read was accomplished in 19 bytes over the UART
~~~~
That's a bit short (19 bytes), but the file is actually 8MB long. It only contains 0x00s, but that could be true, as it is probably not initalized.

ZipCPU, 2019-03-06:
What to do next:do a git pull, and rebuild the project.  Load it onto the device and run netuart, ,giving it the name of the /dev/ttyUSBx file associated with the device.  While netuart is running, run zipload passing it as arguments "-r" and the location of your built cputest file.  (Should be in the sw/board directory).

    cd sw/host; ./zipload -r ../board/cputest

While its loading, fire up a telnet to the console port,

    telnet localhost 6956

Once the design loads, you should see a CPU test run across the screen.

It isn't perfect.  I'm getting a bit of clunkiness when erasing the flash, but if zipload fails you should then be able to rerun it a second time and it will work.

Alternatively, you can run this design in simulation by running,

    cd sim/verilated; ./main_tb ../../sw/board/cputest

Other than taking longer, both should do the same thing.  Further, if you give "main_tb" a -d argument as well as a filename to run, it will generate a trace of the entire encounter.

Dan

NeuerUser, 2019-03-06:
Wow! You are a genius! It's working!!!

Absolutely great! Now I have something to play with and to try to understand how the Soc works in detail. (I'll probably start with the memory structure, e.g. RAM, FLASH, SDRAM(?), etc, and how the CPU is loaded and started.)

Btw, the cputest takes about 2 seconds. It's pretty fast. The loading before takes rather long. It seems that zipload first reads the flash to see if it has already the correct content (taking about a minute), and if not, flashes the right content (taking about 10 min). Would it also be possible to load the program only to RAM? Or does the CPU do XIP on the flash? (so much to learn...)

Anyway, there are still some files missing for someone to simply checkout the repo and compile it in Quartus. I made a small patch. If you want you can include it. It adds the missing files and removes unneeded files. Ah, and it also changes the hostname for the connection to "localhost", as I guess that most people will not run it on a PC with name "jericho", but probably locally.

Thanks again for this great project!
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
ZipCPU, 2019-03-06:
The CPU is currently running in XIP mode from the flash and fetching its instructions from there on an as needed basis.  That means that the instructions themselves are kept on the flash, and read from the flash just before execution.  You can [read about the fetch routine currently in use here](http://zipcpu.com/zipcpu/2018/03/21/dblfetch.html).

There wasn't room to on the device to use the DMA to load the instructions into memory, or to [fully pipeline the CPU](http://zipcpu.com/zipcpu/2017/08/23/cpu-pipeline.html) and use the I-cache.  However, if you adjust the linker script, you can adjust how much code is placed into RAM in the first place.  Further, if you swap to the [RAM only linker script (bkram.ld)](https://github.com/ZipCPU/arrowzip/blob/master/sw/board/bkram.ld), you should be able to run without the flash at all.

While getting the [flash controller](https://github.com/ZipCPU/arrowzip/blob/master/rtl/arrowzip/dualflexpress.v) up and running, I had an 8kB buffer in use for [my logic analyzer](http://zipcpu.com/blog/2017/07/08/getting-started-with-wbscope.html) as [applied to the flash](https://github.com/ZipCPU/arrowzip/blob/master/sw/host/flashscope.cpp).  This 8kB buffer was so large, the CPU block RAM usage was dropped down to 1kB--lower than it needed to be.  In order to get the CPU test to run with this bare minimum of RAM, I had to put all the code on the flash in order to get it to fit.  Only the memory data structures are copied into RAM now as a result, none of the code.  Now that the flash is working, the block RAM memory has been expanded back to 32kB.  To run from memory instead of loading the flash, just use the [bkram.ld linker script](https://github.com/ZipCPU/arrowzip/blob/master/sw/board/bkram.ld) generated by [AutoFPGA](http://zipcpu.com/zipcpu/2018/12/22/autofpga-ld.html).

As for the CPU test being fast .... the multiply test feels painfully slow when running from simulation.  ;)

Yes, loading is *painfully* slow.  Some of that is due to the flash being so slow in general, some of it is due to the light-weight debugging bus used by this project.  (Yes, I am actually sending 88-bits across the interface just to write an 8-bit value to the flash--very inefficient)  Normally I'm using [an interface with a bit more capability](http://zipcpu.com/blog/2017/06/05/wb-bridge-overview.html), but that one wouldn't fit on this chip.  Perhaps the way to fix that would be to write a small ZipCPU program into block RAM, then to write a piece of compressed memory to block RAM next to the CPU program.  The ZipCPU could then decompress the memory segment, read from the flash, determine if the flash needs to be erased, erase the flash, program it, and then verify it.  I've wanted to build a program to do this for some time but ... haven't yet had the opportunity.

BTW, thanks for the hostname catch!  I run from "jericho" here (my own CPU) so that [I can interact with the device from anywhere on my local network](http://zipcpu.com/blog/2017/06/17/why-network-debugging.html).  The ports.h file is *supposed* to reference localhost, which would work on all networks, but ... I must've missed that.  Thank you!

My next steps with this project now include: 1) adding and testing [the SDRAM controller](https://github.com/ZipCPU/arrowzip/blob/master/rtl/arrowzip/wbsdram.v), and 2) figuring out the MEMs device and integrating that into the project!

NeuerUser, 2019-03-06:
Just wondering as you are mentioning the restricted size of the chip several times: The current design uses currently ~5050 LEs (63%). Is the DMA or the faster wb_bridge so big that they wouldn't fit?

Btw. there are two sister boards for the MAX1000: 1.) a bigger MAX1000 with a 16k LE FPGA and 32MB flash and 2.) the Cyc1000, which uses a different FPGA with 25k LEs. I guess, it should be pretty simple to port to these sister boards.

ZipCPU, 2019-03-07:
Now that the SDRAM is a working part of the design, it now uses about 5800/8000 LEs.  I'm not going to place the ZipSystem, containing the DMA, onto the device so that I can leave logic room available for whatever a user might wish to do with it.  Judging from my ORCONF 2017 presentation, I would expect 1k-2k more elements to fully pipeline the CPU, add in the performance counters, DMA, etc.

I still want to install the MEMS sensor and play with that--that one is still on my list of TODO's.

Closed 2019-03-07.

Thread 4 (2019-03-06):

RTC working ?

NeuerUser, 2019-03-06:
Hi Dan

Just a short question: Is it possible that the rtclight module is not really working?

I do have the regs CLOCK, ALARM, TIMER, STOPWATCH, but none of them counts in any case. I can set the regs, but they don't seem to change at all.

But maybe I am missing something...

ZipCPU, 2019-03-06:
I just checked that they were working in simulation the other day, but yeah, I see your point, nothing seems to be changing now.  Further, the clock divider register, used to set the clock speed, isn't named.  If I read from that register (it's 4-bytes after the alarm data), I see that the clock divider (ckspeed in rtclight.v) is set to zero.  It's not supposed to be set at zero, so ... I might need to peel this onion back a step or two.

Perhaps Quartus doesn't like a register with initial but no always block?

ZipCPU, 2019-03-06:
Fixed!  Clock, timer, and stopwatch all work now.  Alarm should work, although I haven't tested it.  You can also read the "CKSPEED" register to see the fractional clock divider.  (You'll need to adjust the OPT_FIXED_SPEED parameter if you want to adjust the clock speed.)

NeuerUser, 2019-03-06:
Sorry to come back again, but I think the stopwatch functionality is broken.
The src code says "write 1" to the reg to start and "0" to stop. "2" clears. However, currently it seems that just every write to it just toggles the running state. So writing "0" also starts, when it is not running, and stops, when it is. Nothing clears the stopwatch.

ZipCPU, 2019-03-07:
Fixed!

NeuerUser, 2019-03-07:
Hi Dan

Sorry to be a pain in the a.., but the stopwatch now stops with every read. So, clearing works, starting and stopping works, but every read also stops the watch.

ZipCPU, 2019-03-07:
Fixed again!  Try it now.

NeuerUser, 2019-03-08:
Hi Dan

Not sure, if I'm doing something wrong. I typically make clean, then pull the latest commits and make the project again (as always, I need to restart make two times in order to have it finish, because of verilator warnings->errors). I then add the qsf and qpf files from quartus and any missing verilog files (e.g. altera_gpio_lite.v). Then compile with quartus and program to the MAX1000.

Anyway, the result is that there is no change to the stopwatch bug. I cannot even see a commit that would fix the bug?!

(But I also have other issues with hello.c and memtest.c, but I will open a new issue for that, in case it is not because of some errornous workflow I am using.)

ZipCPU, 2019-03-08:
So ... I took another look at the stopwatch.  It's still not working, but I can see what's wrong this time.  I'll post a patch as soon as I test my fix.  This newer bug shouldn't be a "no change" issue, however.  It's something you haven't seen before, so if you are seeing "no change" than my best guess is that you haven't updated the design.

I've had no end of trouble with Quartus not updating the SVF file.  It seems like I need to re-open the "program device" dialog every time I want to program the device in order to get the most recent build onto the device.

Check the VERSION and BUILDTIME registers with wbregs.  The version should be 20170307 and the build time 00170606 (or later).  This would explain your other problems too.

NeuerUser, 2019-03-08:
Hi Dan

~~~~
$ ./wbregs version
00800014 ( VERSION) : [....] 20190307
$ ./wbregs buildtime
00800000 (BUILDTIME) : [..(@] 00172840
$ ./wbregs stopwatch
00a00048 (STOPWATCH) : [...p] 00000000
$ ./wbregs stopwatch 2; ./wbregs stopwatch 1; sleep 2; ./wbregs stopwatch; sleep 3; ./wbregs stopwatch
00a00048 (STOPWATCH)-> 00000002
00a00048 (STOPWATCH)-> 00000001
00a00048 (STOPWATCH) : [....] 80000202
00a00048 (STOPWATCH) : [....] 00000202
~~~~
Looks as if I have a newer design on it. But still every read stops the stopwatch.

Maybe something is wrong with my workflow. As I mentioned:
- I have warnings during make, that I can overcome by restarting make
- I still need to add files to the repo in order to get it compiled (see one of my posts before: altera_gpio_lite.sv, Quartus .qpf and qsf files, as well as changing "jericho" to "localhost"

Maybe I should open a new issue and post there my full workflow. Maybe I should also upload my changed repo (with the extra files), so you could try to check it out and build from Quartus.

ZipCPU, 2019-03-08:
No, now your symptoms are matching mine.  That's the fix I'm testing now.  The fix seems to work, so look forward to a post shortly.  (I'll write it here too.)

ZipCPU, 2019-03-08:
How's this?

````text
$ ./wbregs stopwatch 1 ; sleep 2 ; ./wbregs stopwatch; sleep 3; ./wbregs stopwatch
00a00048 (STOPWATCH)-> 00000001
00a00048 (STOPWATCH) : [....] 80000201
00a00048 (STOPWATCH) : [....] 80000502
$
````
Note that the last two digits are 10ths of seconds, so 0x201 says that 2.01 seconds have passed.

Changes are now posted.  I also double checked memtest and it works, as does hello (now--I had to fix a bug in the ZipCPU stubs for the C-library, check out the syscalls.c in sw/zlib if you are interested).

Dan

NeuerUser, 2019-03-08:
Yes, looks good also on my board now. Thanks!

Closed 2019-03-08.

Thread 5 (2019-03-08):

hello.c

NeuerUser, 2019-03-08:
I'm having problems to get any output from the test program "hello".
~~~~
$ ./wbregs version; ./wbregs buildtime
00800014 ( VERSION) : [....] 20190308
00800000 (BUILDTIME) : [....] 00081204
~~~~~

When I start zipload 'hello' the first time, I get an error:
~~~~
 time ./zipload -v -r ../board/hello
ZipLoad: Verbose mode on
Halting the CPU
Loading: ../board/hello
Sending to flash: 01000000-01000134
Sending to flash: 01000134-01004a54
ERASING SECTOR: 01000000
Erasing sector: 000000
SECTOR ERASE FAILED!
ERR: Could not write program to flash

real    1m18.194s
user    0m0.323s
sys     0m1.361s
~~~~
This seems to be the flash erase.

Starting a second time, no flash erase is done. Instead the code is written:
~~~~
$ time ./zipload -v -r ../board/hello                                                            ZipLoad: Verbose mode on
Halting the CPU
Loading: ../board/hello
Sending to flash: 01000000-01000134
Sending to flash: 01000134-01004a54
Writing page: 0x01000000 - 0x010000ff
Writing page: 0x01000100 - 0x010001ff
Writing page: 0x01000200 - 0x010002ff
Writing page: 0x01000300 - 0x010003ff
[...]
Writing page: 0x01004900 - 0x010049ff
Writing page: 0x01004a00 - 0x01004aff
Clearing the CPUs registers
Setting PC to 01000000
Starting the CPU
CPU Status is: 0000000f

real    8m22.885s
user    1m45.880s
sys     4m4.044s
~~~~
After taking this 8,5 min, there is no output visible, neither on telnet session, nor on the netuart console.

If I read the code correctly (which is rather small), it should output "Hello, world!".

ZipCPU, 2019-03-08:
Yes, you should see "Hello, world!" printed onto the console on the telnet port if this program works.

As for the "SECTOR ERASE FAILED" message, I've chased it down some.  The issue appears to be that the flash isn't setting the status register properly to indicate that the flash is busy.  Hence, the controller checks the results of the (still in progress) erase, reads that the erase is no longer busy (when it is), and then starts to read from memory--getting a bad result.  When you read from the flash later, once the flash has finished erasing the memory, then the zipload program sees that the erase is no longer needed and then successfully programs the flash.

Given that the flash isn't returning the right value, I'm not yet certain how to "break the protocol" to fix things.  Perhaps reading the status register twice?

Next, you will also need to rebuild the hello.c program since I adjusted the board linkscript that it depends on.  That and your problem may be the SDRAM, so let's make sure that the memtest passes first.  Based upon your other issue, it isn't.

NeuerUser, 2019-03-09:
Now working after fixing SDRAM. :+1:

Closed 2019-03-09.

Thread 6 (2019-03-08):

output of memtest

NeuerUser, 2019-03-08:
If I read the memtest prog correctly, it should turn on 5 of the 8 LEDs, right?
Well, after starting, the program just turns on all 8 LEDs. No output on telnet or netuart, which is to be expected, right?
~~~~
$ time ./zipload -v -r ../board/memtest
ZipLoad: Verbose mode on
Halting the CPU
Loading: ../board/memtest
Writing to MEM: 00c00000-00c0039c
Clearing the CPUs registers
Setting PC to 00c00000
Starting the CPU
CPU Status is: 0000200f

real    0m4.846s
user    0m1.380s
sys     0m3.431s
~~~~
Loading is pretty fast.

ZipCPU, 2019-03-08:
If all goes well in the memtest, the LEDs should go as follows:

1. *_spio = 0x0f00; // Start out by turning off the bottom four LEDs

  The design then writes to all memory values, sequentially, as though they were integers.  It then comes back and reads all of these integers.  Once complete, it sets the LEDs and moves to the next test.

2. *_spio = 0x0f01; // Turn on the bottom LED

  This is to indicate that the first test passed.

  The next test is a repeat of the first test, save that triplets are read/written to memory at the same time.  This is designed to test memory pipelining--something that requires the pipeline (which isn't turned on) and pipeline memory access.  Hence, this test should succeed or fail the same as the first.

3. *_spio = 0x0f03; // Turn on the bottom two LEDs

  We now go through the memory 3 8-b characters at a time, setting the memory to random values, and checking them three characters (not 32-b integers)

4. *_spio = 0x0f07; // Set the bottom three LEDs

  The next test is a random access test, randomly writing pseudorandom data through memory

5. At the end of this sequence, we toggle the fifth bit and repeat.

If at any time in this process, the SDRAM fails to return an expected value, all LEDs are turned on and the CPU halts.  You can tell that the CPU has halted by running "zipstate".  You can find out why/how it halted, and what the problem was, by first running "make memtest.txt" in sw/board to get disassembled copy of the memtest program.  Second, you'll want to run zipdbg to get the state of the processor when it failed.  The user-space registers will indicate where in the process the program failed.

My guess is that you are struggling with the PLL generation.  The PLL, known as genpll needs to create two clocks, one at 80MHz and a second one 90 degrees offset from it.

NeuerUser, 2019-03-09:
Hi Dan

Now it gets interesting :) Unfortunately, I guess I don't have the knowledge as a beginner here. This is what I got:
~~~~
$ time ./zipload -v -r ../board/memtest
ZipLoad: Verbose mode on
Halting the CPU
Loading: ../board/memtest
Writing to MEM: 00c00000-00c0039c
Clearing the CPUs registers
Setting PC to 00c00000
Starting the CPU
CPU Status is: 0000200f

real    0m4.848s
user    0m1.443s
sys     0m3.370s
$ ./zipstate
0x0000100f: BUSY SW-HALT
$ ./zipdbg
Peripherals                   CPU State: 0x00001613 Halted
>PIC > 0x00c00030<   WDT : 0x00400000    WBUS: 0x88000004    PIC2: 0x00000000
 TMRA: 0x00000000    TMRB: 0x00000000    TMRC: 0x00000000    JIF : 0x00000000
 MTSK: 0x00000000    MOST: 0x00000000    MPST: 0x00000000    MICT: 0x00000000

Supervisor Registers
 sR0 : 0x00c00030    sR1 : 0x00400000    sR2 : 0x88000004    sR3 : 0x00000000
 sR4 : 0x00000000    sR5 : 0x00000000    sR6 : 0x00000000    sR7 : 0x00000000
 sR8 : 0x00000000    sR9 : 0x00000000    sR10: 0x00000000    sR11: 0x00000000
 sR12: 0x00000000    sSP : 0x00c07800    sCC :TPHLT          sPC : 0x00c00394
User Registers
 uR0 : 0x01800000    uR1 : 0x000485b5    uR2 : 0x02000000    uR3 : 0x000485b5
 uR4 : 0x8e648e64    uR5 : 0xffe00000    uR6 : 0x00000001    uR7 : 0x01800000
 uR8 : 0x00800010    uR9 : 0x00000000    uR10: 0x00000f00    uR11: 0x00000000
 uR12: 0x00000000    uSP : 0x00c07fd8    uCC :TP             uPC : 0x00c000c8

                                                     >00c07800 0x00000000
 0x00c0039c 0x00000000  SUB        $0,R0              00c07804 0x00000000
 0x00c00398 0x7b400000  RTN                           00c07808 0x00000000
>0x00c00394 0x68800800  ADD        $2048,SP           00c0780c 0x00000000
 0x00c00390 0x70c00010  HALT                          00c07810 0x00000000
~~~~
The strange thing is that 0x00c00038 is (at least not for me) a reasonable PC, as I cannot see there any HALT (or similar) instruction:
~~~~
memtest:     file format elf32-zip

Disassembly of section .ramcode:

00c00000 <_start>:
  c00000:       86 00 8e 00     CLR        R0             | CLR        R1
  c00004:       96 00 9e 00     CLR        R2             | CLR        R3
  c00008:       a6 00 ae 00     CLR        R4             | CLR        R5
  c0000c:       b6 00 be 00     CLR        R6             | CLR        R7
  c00010:       c6 00 ce 00     CLR        R8             | CLR        R9
  c00014:       d6 00 de 00     CLR        R10            | CLR        R11
  c00018:       66 00 00 00     CLR        R12
  c0001c:       6a 01 03 00     LDI        0x00c08000,SP  // c08000 <_top_of_stack>
  c00020:       6a 40 80 00
  c00024:       76 00 00 00     TRAP
  c00028:       87 fa fc f8     JSR        0x00c002d4     // c002d4 <entry>
  c0002c:       00 c0 02 d4

00c00030 <busy_failure>:
  c00030:       78 83 ff fc     BUSY

00c00034 <runtest>:
  c00034:       e8 24 85 00     SUB        $36,SP         | SW         R0,(SP)
  c00038:       ad 04 b5 08     SW         R5,$4(SP)      | SW         R6,$8(SP)
  c0003c:       bd 0c c5 10     SW         R7,$12(SP)     | SW         R8,$16(SP)
  c00040:       cd 14 d5 18     SW         R9,$20(SP)     | SW         R10,$24(SP)
  c00044:       dd 1c e5 20     SW         R11,$28(SP)    | SW         R12,$32(SP)
  c00048:       42 00 01 00     LDI        0x00800010,R8  // 800010 <_kram+0x800010>
  c0004c:       42 40 00 10
  c00050:       06 00 ff 00     LDI        $65280,R0
  c00054:       04 c6 00 00     SW         R0,(R8)
  c00058:       02 00 02 00     BREV       $512,R0
  c0005c:       8e 04 8d 80     LDI        $4,R1          | SW         R1,(R0)
 ~~~~
I did the test two times. In between I did a "make clean", "make" and "make memtest.txt", to ensure that everything has been rebuild.

Looking at Quartus, I cannot see anything in the verilog concerning the pll that differs from your repo. (I only added files for the altera_lite_gpio.) Also  ......

SORRY, JUST FOUND THE PROBLEM!!!! (Completely stupid!!!) I did not update my qsf file after you enabled the SDRAM, so there are NO PINS defined for the connection to the SDRAM. (So stupid from me!!!!). I will just do that now and then retest it.

NeuerUser, 2019-03-09:
So, that HELPED! Now the memtest is working. :)

The third led is not visible, however. It is possible that it is turned on and directly after that off again. The fifth one is toggling slowly.

ZipCPU, 2019-03-09:
Yeah, the 3rd LED gets turned off so fast that you don't notice it much.  You will notice that all the LEDs don't turn on, and that the 5th LED toggles (slowly)--indicating success.

But let's talk a moment about that 0x0c00038 address you were looking at.  I'm not sure where you found it from.  If you look left of the HALT, you'll see that the CPU halted at instruction 0xc00390.  The SPC (Supervisor program counter) points to the next instruction, 0x0c00394.  Most of the program runs in user mode, after the supervisor issues the RTU command (zip_rtu() in the code).  That's where the test is run.  Upon any detection of a failure, the CPU issues a "TRAP" function to switch to supervisor mode.  Hence, the registers you really want to be looking at are the u* registers.

If you look at the uPC register, you'll see that the program stopped at 0xc00c8.  This is one past the TRAP instruction which sent us back to supervisor space.  (Yes, the *PC points to the next instruction, rather than the one just executed.)

If you back up a bit further, you'll see a BZ instruction (branch on zero).  This follows the test that the value read from memory equals the value written.  If they are equal, the CPU will jump to 0x0c00c8 and skip the TRAP instruction.

Backing up two more, you'll see where the CPU reads from memory (LW (R0), R4, or load a word from address R0 into register R4), followed by a compare (CMP R3,R4) comparing registers R3 with R4.

This means you can look at uR0, uR3, and uR4 (remember, this part is in user mode) to see what's going on.  uR0 = 0x01800000, which is the very first address in RAM.  This means we failed on the very first check, much like what you discovered with a bad pinout.  If you look at uR4, you get 0x8e648e64, the value we just read from memory.  Now, remember how the memory is  a 16'bit memory, but the bus is 32-bits?  That means that to read from the memory we needed to do two separate reads and piece them together.  This value shows that, of those two separate reads, they both read the same value.  This is again consistent with a bad pinout, although it could have been other things.  What was the value supposed to be?  That's in R3, and it is set at 0x0485b5.

If you look back any further, you'll see a MOV R6,R3.  That moves the "counts" value (R6==1) into the LFSR fill register kept in R3.  LDI 0x01800000 is a long (two word) instruction to load 0x01800000 (the address of the beginning of memory) into R0.  LSR 1,R3 is the first of a two step instruction to run the LFSR, basically shifting all the bits right (R3 >>= 1).  Remember, R3 was just set to R6, and so it starts out as one.  Shifting it right by one turns it into a zero.  Unlike many other architectures I know of, this also sets the carry bit to what used to be R3&1.  That means that, on the next instruction, if the carry was set (it was), I exclusive or R1 (the taps register, 0x0485b5) with R3 (the fill register which had just turned zero) to get the memory value 0x485b5.

LFSR's psudorandom number generators.  They aren't true random number generators, but they tend to be low cost and (in this case) repeatable.  Here, I start with "counts" and run the LFSR to generate a bunch of random numbers that are then written to the memory, and then *repeat the random sequence* when reading the results back from memory in order to check that I got the right values back.

In all, I'm excited for you, and glad you got it running.

Dan

NeuerUser, 2019-03-10:
Hi Dan

Thanks for the great explanation. Just for completeness, I found the 0x00C000c8 in the above shown screenshot of zipdbg as the uPC.

I am also very excited. It's so great to have this fascinating full soc on that small board and being able to learn how it works, and finally even being able to modify it. Thanks a lot for publishing this!

(I will probably open some other issues in the next days, e.g. if I have problems, questions or suggestions.)

Closed 2019-03-09.

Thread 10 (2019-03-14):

Support for CYC1000

NeuerUser, 2019-03-14:
The CYC1000 (https://www.arrow.com/en/products/cyc1000/arrow-development-tools) is a sister board of the MAX1000. It is very similar, in size as well as the components used. The main difference is the FPGA. Instead of a MAX FPGA it is a 10CL025YU256C8G. This differs in so far as it is a.) much bigger (24kLE compared to the 8kLE of the MAX10, and twice the amount of RAM), b.) uses external flash to store its configuration and 3.) doesn't support analog inputs.

Interestingly, it is very easy to compile and run the arrowzip on that board with only minimal changes:
~~~~
Fitter Status	Successful - Thu Mar 14 11:05:45 2019
Quartus Prime Version	18.1.0 Build 625 09/12/2018 SJ Lite Edition
Revision Name	CYC1000Zip
Top-level Entity Name	toplevel
Family	Cyclone 10 LP
Device	10CL025YU256C8G
Timing Models	Final
Total logic elements	5,568 / 24,624 ( 23 % )
Total registers	3025
Total pins	54 / 151 ( 36 % )
Total virtual pins	0
Total memory bits	265,216 / 608,256 ( 44 % )
Embedded Multiplier 9-bit elements	16 / 132 ( 12 % )
Total PLLs	1 / 4 ( 25 % )
~~~~
All test programs (cputest, memtest and hello) all work perfectly fine!
The changes needed to get this working are very little:

- new pin definition file (qsf)
- exchange of the yaddro and yaddrio functions

There are still some small issues to be tackled:

1. The SPI flash is only 2MB big. The first MB is used to store the FPGA config and should not be accessible.
2. The FPGA has twice as much RAM, which could be used.

Can you direct me how best to change these settings? I guess they are somewhere in auto-data, right?

And how would you think it makes most sense to manage this revision? Adding a new branch within git or better a revision within Quartus?

ZipCPU, 2019-03-14:
Changing the flash size is the easy part.  The size of the flash should be completely parameterized by the @$LGFLASHSZ tag in auto-data/flexpress.txt.  Adjust that, rerun autofpga, and everything should be back to normal.

The same is true of adjusting the amount of block RAM: if y ou adjust @$LGMEMSZ in auto-data/bkram.txt, and re-run AutoFPGA, you'll have a new design updated for the new RAM size.

There is a consequence of these changes, however, you'll need to adjust the default ZipCPU boot address.  This would be used in case you want the ZipCPU to start on a power up.  (It's currently set to start halted, but that's a one-bit parameter change in auto-data/zipbones.txt).  Specifically, inside auto-data/zipbones.txt, you'll want to adjust the @$RESET_ADDRESS tag to point to roughly a quarter of the way into the flash--or wherever it will not interfere with the design image file.  Perhaps something like:

@$RESET_ADDRESS=@$(flash.REGBASE)+@$(flash.NBYTES)/4

As far as managing the revision ... I'm not sure.  I'm open to suggestions.

Dan

NeuerUser, 2019-03-14:
Hi Dan
Is it also possible to allow the FPGA access to only the second half of the flash? A small write to the first would render the FPGA image defect.

ZipCPU, 2019-03-14:
Anything is possible.  But I think you are asking the wrong question.  I think what you want is a that will never change the FPGA image, not one that doesn't allow the ZipCPU access to read the FPGA image.  Since reading and writing are handled in software, that would need to be handled in the [flashdrvr.cpp](https://github.com/ZipCPU/arrowzip/blob/master/sw/host/flashdrvr.cpp) which issues the erase/write commands.  The actual [flash controller](https://github.com/ZipCPU/arrowzip/blob/master/rtl/arrowzip/dualflexpress.v) is designed to be so simple and bare bones that you can issue any command to it.  Indeed, it assumes that you are old enough to be responsible with your hardware.

NeuerUser, 2019-03-15:
> As far as managing the revision ... I'm not sure. I'm open to suggestions.

Well, the code is pretty identical. Just a new qsf file, two different yaddr(i)o.v files, and two changes in two auto-data files, right?

So, I think the easiest to maintain that, and make it easy to synthesize is probably this approach:

- Keep a single GIT repo. No need to split up the repo or to use different branches. One single branch should suffice.
- allow an option to "make", e.g. "make cyc1000". The only difference should be that is includes two different auto-data files to adapt for the bkram and the flash size. e.g. "bkram-cyc1000.txt " and "flexpress-cyc1000.txt".
- In Quartus, we could use two "revisions", which only instructs Quartus to use a different qsf file. The qsf file contains the pin assignments and also the included files. So the one for teh MAX1000 and the one for the CYC1000 would include different "yaddr(i)o.v" files, one with the two files for the MAX, the other using the two files I created for the CYC1000.

I have already setup the second half of that (the Quartus part) and am trying to adapt the makefiles. Let's see if I can get it working.

ZipCPU, 2019-03-30:
Ok, I finally took a look at the CYC1000 today.  It doesn't look like it would be nearly as thought as I was expecting to create a CYC1000 repository or (better yet) to adjust this repository to handle both.  I can also see how/why the argument for keeping a single repository would work.

Sadly, I don't have a CYC1000, so I'm not (yet) certain how I'd move forward with this issue.

Closed 2019-03-30.

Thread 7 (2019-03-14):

Flash erase not recognizing finished erase

NeuerUser, 2019-03-14:
Hi Dan

As you already mentioned, there is an issue with the flash controller not recognizing the finished erase cycle. I thought I could make sense to follow that issue with a separate issue. So, here is the info:

~~~~
$ ./wbregs version
00600014 ( VERSION) : [....] 20190309
$ ./wbregs buildtime
00600000 (BUILDTIME) : [..GC] 00114743
$ ./zipload -v -r ../board/hello
ZipLoad: Verbose mode on
Halting the CPU
Loading: ../board/hello
Sending to flash: 01000000-01000134
Sending to flash: 01000134-01004a54
ERASING SECTOR: 01000000
Erasing sector: 000000
~~~~
** [not finishing at all even after 20 min]**
~~~~
$ ./zipload -v -r ../board/hello
ZipLoad: Verbose mode on
Halting the CPU
Loading: ../board/hello
Sending to flash: 01000000-01000134
Sending to flash: 01000134-01004a54
Writing page: 0x01000000 - 0x010000ff
Writing page: 0x01000100 - 0x010001ff
[...]
Writing page: 0x01004900 - 0x010049ff
Writing page: 0x01004a00 - 0x01004aff
Clearing the CPUs registers
Setting PC to 01000000
Starting the CPU
CPU Status is: 0000000f
~~~~
A second start then recognizes that the flash is erased and starts writing.

ZipCPU, 2019-03-14:
This should be fixed in the current repo by the line line "flashcfg_data = flash_data" in main.v.  Please double check that you have this line, git pull otherwise, and let me know if this is still an issue.

NeuerUser, 2019-03-15:
Yes, I can confirm that this line is in main.v. And the version and buildtime show that this design is really loaded on the board.

ZipCPU, 2019-03-15:
Looking over this again, it looks like I read it too fast.

Can you provide a copy of whatever's going on in the netuart output when the design fails?

Thanks!

Dan

NeuerUser, 2019-03-15:
yeah, tons of
~~~~
< R
> Rffffffff
< R
> Rffffffff
< R
> Rffffffff
< R
> Rffffffff
< R
> Rffffffff
< R
> Rffffffff
~~~~

ZipCPU, 2019-03-15:
Ok, that means its still going.  It's likely in the process of verifying the erase, or perhaps checking if the next sector needs to be erased.

Specifically, "R" is a command from the host to the device, asking it to read either the same address or the next address (depending on the start of the operation.   The device responds with "Rffffffff" saying that it has read the value, and it is an 0xffffffff

So ... it's working, just slowly.

ZipCPU, 2019-03-30:
I'm going to close this "flash" issue as well.  The design is worked as it was intended, it is just horrendously slow across the debugging bus.  I'd like to come back and speed it up, but that should really be filed under another issue.

Closed 2019-03-30.

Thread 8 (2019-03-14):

dumpflash not working

NeuerUser, 2019-03-14:
Before this test I had run "hello", so that the flash got successfully written to.
~~~~
 ./wbregs version
00600014 ( VERSION) : [....] 20190309
$ ./wbregs buildtime
00600000 (BUILDTIME) : [..GC] 00114743
$ time ./dumpflash
Before starting, nread = 0
VERSION: 20190309

READ-COMPLETE
The read was accomplished in 19 bytes over the UART

real    0m0.019s
user    0m0.000s
sys     0m0.013s
~~~~
The file is 8MB large, but contains only zeros.

ZipCPU, 2019-03-14:
Try a git pull.  I had that problem with an earlier version, and everything is working properly for me now.

NeuerUser, 2019-03-15:
I am on commit b9509a2f8ba3b568af51939232b86f58773a00c1 (so, only the port.h commit missing). I rebuilt all programs via "make clean" and "make" in the sw/host directory. Same result.

ZipCPU, 2019-03-15:
Ok, I see the bug here ... I was chasing down a bus error some time ago (never found it) in dumpflash, and so I had modified the code so that it would look only at the end of the flash.

I just pushed a working version of dumpflash.cpp to the repo.  Let me know if that works for you.

NeuerUser, 2019-03-15:
Yes, seems to work now. (but taking ages, of course, so I probably will cancel the transfer before it is finished...)

ZipCPU, 2019-03-15:
Yes to taking ages.  I think I left it running for about 10 hrs before it finally got to the end.

ZipCPU, 2019-03-15:
Also ... the vector read is about 3x faster, but I turned that off in case you wanted to interrupt it mid-way.  I might go back to vector reads, but instead to doing them in chunks so that you can interrupt it and get the results, while also having it run 3x as fast.

Closed 2019-03-15.

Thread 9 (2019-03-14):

Great article

NeuerUser, 2019-03-14:
Hi Dan

I read your article (http://zipcpu.com/zipcpu/2019/03/12/arrowzip.html). It is really very well written and contains lots of useful information. Thanks for publishing that!

I have a couple of remarks from my side as a beginner/user here:

### Missing files in repo:
Great that you could get rid of the altera_gpio_lite file. Still, the repo is having some small changes needed in order to make it usable as is: 1.) it needs the pin definition file (qsf) 2.) "port.h" still has as a default the "jericho" hostname instead of "localhost" and 3) "sw/board/Makefile" is referring to "/home/dan/work/..." (I replaced that with a relative path; not sure though if that would be the best approach)
I can send you a small patch that adds the missing files and fixes the "jericho". These are really minor changes (the last 0.01%), but could help newbies like me.
### Interface and Flash speed:
I completely agree. That is a major issue. If you really want to write programs that run on the arrowzip, then you can't always wait for 10 min to flash a simple "Hello World". I have no idea, howto fix this. Maybe a mixture of a faster interface (using compression?) and flashing locally via small helper program on zipcpu.
A faster communication would also help with zipdbg. Currently it takes about 5 seconds to move the cursor. So, for real on device debugging, it is rather useless. What do you think?

### "Missing" functionality, e.g. accelerator
While I also think that the accelerator is not really needed, it would be fun to have. Additionally, there are also ADCs on the board that can read from several analog input pins (and even with the possibility to read the temperature of the board). And let's not forget there are of course many digital I/Os, which would be nice to be able to use. So, on top of the accelerator module, a module for GPIO usage and one for analog inputs would be great.

### Size of the Soc on the FPGA:
While I agree that 5700 is not really "slim", I do think it doesn't matter. I believe that, instead, everything should be included that makes sense on the board, even if it goes up to 100% usage. Why? Because due to your great AutoFPGA, it should easily be possible for the user to comment out blocks such as the RTC etc, if the user needs more free space on the FPGA. Adding stuff is always more difficult than removing. So, I'd love to see a faster communication module, GPIO, ADC and accelerator support included, with the possibility to easily comment them out of the Makefile, if not needed.

As mentioned, these are just small suggestions. Your arrowzip is a great piece of work. I am sure many users of the MAX1000 will try it out.

ZipCPU, 2019-03-14:
1. The port.h issues has been fixed.
2. Including pin definitions is a marvelous idea.
3. Would love to hear a better solution to the hard path in sw/board/Makefile.  I agree that it's an issue.

## The slow flash speed

My plan for the slower flash speed is to integrate two ZipCPU programs into the flash loader.   There's a little bit of trickery required of the compiler, since I'd want these two programs to remain the same even if the block RAM or the flash address(es) change.  When done right, it'll keep the loader from needing to send the same data across the slow interface about 6 times.  As currently designed, two ZipCPU programs will be used: an erase function of about 500 bytes and a write function of 830 bytes, including the data to be written.  So, ... this is currently a work in progress.

If you want to be a part of working on this at all, then I can put my chicken-scratches into a new branch where you can see what's going on and the plan for moving forward.  Similarly, the conversation on this topic should be moved to a new thread ... just to keep things focused and easy to find.

## The slow debugger

Sadly, this is a known issue, and it dates back to how I built the zipbones/zipsystem debugging interface.  These really need to be updated with a newer interface sporting a separate address per register.  This would fix the issue, but it would also break every program I have using that interface.  This has kept it from the forefront so far.

## Size of the SoC

The size of the SoC is what makes this the ArrowZip project as opposed to the OpenArty (autoarty branch right now for AutoFPGA), the VideoZip project, the TinyZip project, or even the IcoZip project.  All of these projects share a *large* amount of code, and use AutoFPGA to control their various interfaces.  If you look around, you'll find the faster/pipelined CPU in the OpenArty and VideoZip projects, together with the faster/compressed debugging bus.  You'll also find a GPIO module in those projects that would be nice to move over into this one.

This project, though, will be unique in supporting the accelerometer+A/D, since I don't have that chip on any of my other boards.

Dan

NeuerUser, 2019-03-15:
>     3\. Would love to hear a better solution to the hard path in sw/board/Makefile.  I agree that it's an issue.

I guess there is no perfect solution. I opted for using a relative path which assumes that you have the ZipCPU repo and the ArrowZip repo as two folders in parallel in the same directory.
So:
~~~~
INSTALLD=../../../zipcpu/sw/install
~~~~
That assumes the following structure:
~~~~
-- some_dir
          -- zipcpu
                     -- ...
          -- arrowzip
                     -- ...
~~~~

ZipCPU, 2019-03-30:
I'm closing this issue, in spite of the hard-path problem.  Feel free to open a hard path issue if it's still a problem for you.

Closed 2019-03-30.

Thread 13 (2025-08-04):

Try to build on 'core max10' board

danielitzahi, 2025-08-04:
Hi dan
I want to try this project
On 'core max10' board https://vhdplus.com/docs/components/vhdpcore_max10/
Same 10M08SAU169C8G
Same sdram
Same flash

I successfull to build this project
But no success with quartus vqm file
I got error on quartus18.1 21.1
Which quartus version need to success?

Tzahi

danielitzahi, 2025-08-04:
[build.yslog.txt](https://github.com/user-attachments/files/21585674/build.yslog.txt)

danielitzahi, 2025-08-06:
Hi dan
i success to Synthesis with quartus
without vqm file
best regards

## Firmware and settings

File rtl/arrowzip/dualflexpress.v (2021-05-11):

////////////////////////////////////////////////////////////////////////////////
//
// Filename:	dualflexpress.v
// {{{
// Project:	ArrowZip, a demonstration of the Arrow MAX1000 FPGA board
//
// Purpose:	To provide wishbone controlled read access (and read access
//		*only*) to the DSPI flash, using a flash clock equal to the
//	system clock, and nothing more.  Indeed, this is designed to be a
//	*very* stripped down version of a flash driver, with the goal of
//	providing 1) very fast access for 2) very low logic count.
//
//	Three modes/states of operation:
//	1. Startup/maintenance, places the device in the dual XIP mode
//	2. Normal operations, takes 33 clocks to read a value
//	   - 16 subsequent clocks will read a piped value
//	3. Configuration--useful to allow an external controller issue erase
//		or program commands (or other) without requiring us to
//		clutter up the logic with a giant state machine
//
//	STARTUP
//	 1. Waits for the flash to come on line
//		Start out idle for 300 uS
//	 2. Sends a signal to remove the flash from any DSPI read mode.  In our
//		case, we'll send several clocks of an empty command.  In SPI
//		mode, it'll get ignored.  In QSPI mode, it'll remove us from
//		DSPI mode.
//	 3. Explicitly places and leaves the flash into DSPI mode
//		0xEB 3(0xa0) 0xa0 0xa0 0xa0 4(0x00)
//	 4. All done
//
// Creator:	Dan Gisselquist, Ph.D.
//		Gisselquist Technology, LLC
//
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
// This program is distributed in the hope that it will be useful, but WITHOUT
// ANY WARRANTY; without even the implied warranty of MERCHANTIBILITY or
// FITNESS FOR A PARTICULAR PURPOSE.  See the GNU General Public License
// for more details.
//
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
// License:	GPL, v3, as defined and found on www.gnu.org,
//		http://www.gnu.org/licenses/gpl.html
//
//
////////////////////////////////////////////////////////////////////////////////
//
//
`default_nettype	none
//
// 290 raw, 372 w/ pipe, 410 cfg, 499 cfg w/pipe
// }}}
module	dualflexpress(i_clk, i_reset,
		i_wb_cyc, i_wb_stb, i_wb_we, i_wb_addr, i_wb_data, i_wb_sel,
			o_wb_stall, o_wb_ack, o_wb_data,
		i_cfg_cyc, i_cfg_stb, i_cfg_we, i_cfg_data, i_cfg_sel,
			o_cfg_stall, o_cfg_ack, o_cfg_data,
		o_dspi_sck, o_dspi_cs_n, o_dspi_mod, o_dspi_dat, i_dspi_dat,
		o_dbg_trigger, o_debug);

	//
	// LGFLASHSZ is the size of the flash memory.  It defines the number
	// of bits in the address register and more.  This controller will only
	// support flashes with 24-bit or less addresses--it doesn't support
	// the 32-bit address flash chips.
	parameter	LGFLASHSZ=24;
	//
	// OPT_PIPE makes it possible to string multiple requests together,
	// with no intervening need to shutdown the QSPI connection and send a
	// new address
	parameter [0:0]	OPT_PIPE    = 1'b1;
	//
	// OPT_CFG enables the configuration logic port, and hence the
	// ability to erase and program the flash, as well as the ability
	// to perform other commands such as read-manufacturer ID, adjust
	// configuration registers, etc.
	parameter [0:0]	OPT_CFG     = 1'b1;
	//
	// OPT_STARTUP enables the startup logic
	parameter [0:0]	OPT_STARTUP = 1'b1;
	//
	parameter	OPT_CLKDIV = 0;
	//
	// OPT_ODDR will be true any time the clock has no clock division
	localparam [0:0]	OPT_ODDR = (OPT_CLKDIV == 0);
	//
	// CKDV_BITS is the number of bits necessary to represent a counter
	// that can do the CLKDIV division
	localparam 	CKDV_BITS = (OPT_CLKDIV == 0) ? 0
				: ((OPT_CLKDIV <   2) ? 1
				: ((OPT_CLKDIV <   4) ? 2
				: ((OPT_CLKDIV <   8) ? 3
				: ((OPT_CLKDIV <  16) ? 4
				: ((OPT_CLKDIV <  32) ? 5
				: ((OPT_CLKDIV <  64) ? 6
				: ((OPT_CLKDIV < 128) ? 7
				: ((OPT_CLKDIV < 256) ? 8 : 9))))))));
	//
	// RDDELAY is the number of clock cycles from when o_dspi_dat is valid
	// until i_dspi_dat is valid.  Read delays from 0-4 have been verified
	// DDR Registered I/O on a Xilinx device can be done with a RDDELAY=3
	// On Intel/Altera devices, RDDELAY=2 works
	// I'm using RDDELAY=0 for my iCE40 devices
	//
	parameter	RDDELAY = 0;
	//
	// NDUMMY is the number of "dummy" clock cycles between the 24-bits of
	// the Quad I/O address and the first data bits.  This includes the
	// two clocks of the Quad output mode byte, 0xa0.  The default is 10
	// for a Micron device.  Windbond seems to want 2.  Note your flash
	// device carefully when you choose this value.
	//
	parameter	NDUMMY = 8;
	//
	// For dealing with multiple flash devices, the OPT_STARTUP_FILE allows
	// a hex file to be provided containing the necessary script to place
	// the design into the proper initial configuration.
	// Verilator lint_off UNUSED
	parameter	OPT_STARTUP_FILE="";
	// Verilator lint_on  UNUSED
	//
	//
	//
	//
	localparam [4:0]	CFG_MODE =	12;
	// localparam [4:0]	QSPEED_BIT = 	11; // Not supported
	localparam [4:0]	DSPEED_BIT = 	10;
	localparam [4:0]	DIR_BIT	= 	 9;
	localparam [4:0]	USER_CS_n = 	 8;
	//
	localparam [1:0]	NORMAL_SPI = 	2'b00;
	localparam [1:0]	DUAL_WRITE = 	2'b10;
	localparam [1:0]	DUAL_READ = 	2'b11;
	localparam [7:0] DIO_READ_CMD = 8'hbb;
	//
	localparam	AW=LGFLASHSZ-2;
	localparam	DW=32;
	//
`ifdef	FORMAL
	localparam	F_LGDEPTH=$clog2(3+RDDELAY);
	reg	f_past_valid;
`endif
	//
	//
	input	wire			i_clk, i_reset;
	//
	// Flash memory port
	input	wire			i_wb_cyc, i_wb_stb, i_wb_we;
	input	wire	[(AW-1):0]	i_wb_addr;
	input	wire	[(DW-1):0]	i_wb_data;
	input	wire	[DW/8-1:0]	i_wb_sel;
	//
	output	wire			o_wb_stall, o_wb_ack;
	output	reg	[(DW-1):0]	o_wb_data;
	//
	// Configuration port
	input	wire			i_cfg_cyc, i_cfg_stb, i_cfg_we;
	input	wire	[(DW-1):0]	i_cfg_data;
	input	wire	[DW/8-1:0]	i_cfg_sel;
	//
	output	wire			o_cfg_stall, o_cfg_ack;
	output	wire	[(DW-1):0]	o_cfg_data;
	//
	output	reg		o_dspi_sck;
	output	reg		o_dspi_cs_n;
	output	reg	[1:0]	o_dspi_mod;
	output	wire	[1:0]	o_dspi_dat;
	input	wire	[1:0]	i_dspi_dat;
	// Debugging port
	output	wire		o_dbg_trigger;
	output	wire	[31:0]	o_debug;

	//
	//
	// Arbitrated bus registers and inputs
	//
	wire		bus_cyc, bus_stb, bus_we, ign_wb_err, ign_cfg_err;
	wire	[(AW-1):0]	bus_addr;
	wire	[31:0]	bus_data;
	wire	[3:0]	bus_sel;
	reg		bus_stall, bus_ack;
	wire		cfg_bus_stb, mem_bus_stb;

	generate if (OPT_CFG)
	begin
		wire	cfg_bus_grant;
		//
		// Memory vs Configuration bus arbiter
		//
		wbarbiter #(
			// {{{
			.DW(DW), .AW(AW+1), .SCHEME("PRIORITY")
`ifdef	FORMAL
			, .F_MAX_STALL(0),
			.F_MAX_ACK_DELAY(0)
`endif
			// }}}
		) arbiter(
			// {{{
			i_clk, i_reset,
			i_wb_cyc, i_wb_stb, i_wb_we, { 1'b0, i_wb_addr },
				i_wb_data, i_wb_sel,
				o_wb_stall, o_wb_ack, ign_wb_err,
			i_cfg_cyc, i_cfg_stb, i_cfg_we, { 1'b1, i_wb_addr },
				i_cfg_data, i_cfg_sel,
				o_cfg_stall, o_cfg_ack, ign_cfg_err,
			bus_cyc, bus_stb, bus_we, { cfg_bus_grant, bus_addr }, bus_data, bus_sel,
				bus_stall, bus_ack, 1'b0
			// }}}
		);

		assign	cfg_bus_stb = bus_stb &&  cfg_bus_grant;
		assign	mem_bus_stb = bus_stb && !cfg_bus_grant;
		assign	o_cfg_data = o_wb_data;
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

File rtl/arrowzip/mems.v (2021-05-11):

////////////////////////////////////////////////////////////////////////////////
//
// Filename: 	rtl/arrowzip/mems.v
// {{{
// Project:	ArrowZip, a demonstration of the Arrow MAX1000 FPGA board
//
// Purpose:	This is the LIS3DH SPI controller.  Please reference the
//		data sheet for the LIS3DH when examining this file.
//
//	The LIS3DH consists of a series of registers that can both be read
//	and written.  This particular controller provides both read and write
//	access to the LIS3DH registers.
//
//	One natural way to have done this would be to stall the WB bus while
//	this controller was being accessed.  This stall would amount to
//	up to 250 clock cycles--unacceptable.  So instead, reads or writes
//	to the device take place via writes to this controller.
//
//	Writes to addresses ...
//	 0- 31	Will read the  8-bit register 0-31
//	32- 63	Will read the 16-bit register, starting at register 0-31
//	64- 95	Will *WRITE* to the  8-bit register 0-31
//	96-127	Will *WRITE* to 16-bit register, starting at 0-31
//
//	Certain registers, however, are *illegal* to write to.  These are the
//	*reserved registers*.  The data sheet warns that attempts to write
//	these registers will damage the device.  Hence, there's a protection
//	circuit to prevent these illegal registers from being written to.
//
//	Reads from this controller will always return the last register read,
//	regardless of the address.
//
//	- If the device is busy, the top bit (o_wb_data[31]) will be set, so
//		you can know to read again later for the right value.
//	- If the the last request was for an 8-bit value, the bottom 8-bits
//		[7:0] will return this result
//	- If the the last request was for an 16-bit value, the bottom 16-bits
//		[15:0] will return this result
//
//		According to the LIS3DH data sheet, 16-bit values will start
//		with the lower [7:0] bits and then return the [15:8] bits.
//		To make certain that these values are coherent, OPT_SWAP_ENDIAN
//		is set by default to swap the two octets before returning the
//		answer.
//
//	Look for examples of how to work with this motion sensor in the
//	sw/board directory.  (None exist there .... yet)
//
// Creator:	Dan Gisselquist, Ph.D.
//		Gisselquist Technology, LLC
//
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
// This program is distributed in the hope that it will be useful, but WITHOUT
// ANY WARRANTY; without even the implied warranty of MERCHANTIBILITY or
// FITNESS FOR A PARTICULAR PURPOSE.  See the GNU General Public License
// for more details.
//
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
////////////////////////////////////////////////////////////////////////////////
//
`default_nettype	none
// }}}
module	mems(i_clk, i_reset,
		i_wb_cyc, i_wb_stb, i_wb_we, i_wb_addr, i_wb_data,
			o_wb_ack, o_wb_stall, o_wb_data,
			o_int, o_done,
		o_mems_cs_n, o_mems_sck, o_mems_mosi, i_mems_miso,
		i_mems_int, o_debug);
	parameter	SCKBITS = 4;
	parameter	[(SCKBITS-1):0]	SPI_CLK_DIVIDER = 5;
	parameter	[0:0]	OPT_SWAP_ENDIAN = 1;
`ifdef	FORMAL
	parameter [0:0]	F_OPT_COVER = 0;
`endif
	input	wire		i_clk, i_reset;
	//
	input	wire		i_wb_cyc, i_wb_stb, i_wb_we;
	input	wire	[7:0]	i_wb_addr;
	input	wire	[31:0]	i_wb_data;
	//
	output	reg		o_wb_ack;
	output	wire		o_wb_stall;
	output	wire	[31:0]	o_wb_data;
	//
	output	wire	[1:0]	o_int;
	output	reg		o_done;
	//
	output	reg		o_mems_cs_n, o_mems_sck, o_mems_mosi;
	input	wire		i_mems_miso;
	//
	input	wire	[1:0]	i_mems_int;
	//
	output	wire	[31:0]	o_debug;

	reg		short;
	reg	[23:0]	data_reg;
	reg	[24:0]	busy_reg, done_pipe;

	wire		spi_busy;
	reg	[15:0]	read_data;
	wire		done;
	reg	[15:0]	wb_return;
	//
	reg		reserved_register;
	reg		oe;
	wire		auto_addr_increment;


	//
	// The clock divider
	//
	reg			spi_ztimer, spi_request;
	reg	[(SCKBITS):0]	spi_timer;

	initial	spi_ztimer = 1'b0;
	initial	spi_timer = { SPI_CLK_DIVIDER, 1'b0 };
	always @(posedge i_clk)
	if ((spi_ztimer)&&(spi_request))
		spi_timer <= {1'b0, SPI_CLK_DIVIDER-1'b1 };
	else if ((!o_mems_cs_n)&&(spi_ztimer))
		spi_timer <= {1'b0, SPI_CLK_DIVIDER-1'b1 };
	else if (!spi_ztimer)
		spi_timer <= spi_timer - 1'b1;

	always @(posedge i_clk)
	if ((spi_ztimer)&&(spi_request))
		spi_ztimer <= 1'b0;
	else if ((!o_mems_cs_n)&&(spi_ztimer))
		spi_ztimer <= 1'b0;
	else
		spi_ztimer <= (spi_timer[SCKBITS:1] == 0);

`ifdef	FORMAL
	initial	assert(SPI_CLK_DIVIDER > 1);
	always @(*)
		assert(spi_ztimer == (spi_timer == 0));
	always @(*)
		assert(spi_timer <= { SPI_CLK_DIVIDER, 1'b0 });
	always @(*)
	if (!o_mems_cs_n)
		assert(spi_timer <= { 1'b0, SPI_CLK_DIVIDER });
`endif

	always @(*)
	begin
		reserved_register = 0;
		casez(i_wb_addr[5:0])
		6'b00_00??: reserved_register = 1;
		6'b00_010?: reserved_register = 1;
		6'b00_0110: reserved_register = 1;
		//
		6'b00_1110: reserved_register = 1;
		6'b01_0???: reserved_register = 1;
		6'b01_10??: reserved_register = 1;
		6'b01_110?: reserved_register = 1;
		default: begin end
		endcase

		oe = (i_wb_addr[7] && !reserved_register);
	end

	assign	spi_busy = (!spi_ztimer)||(busy_reg[24]);
	assign	auto_addr_increment = 1'b1;

	initial	short = 1'b0;
	initial	spi_request = 1'b0;
	initial	o_mems_sck  = 1'b1;
	initial	o_mems_cs_n = 1'b1;
	initial	busy_reg    = 0;
	initial	data_reg    = 0;
	initial	done_pipe    = 0;
	always @(posedge i_clk)
	begin
		spi_request   <= (i_wb_stb)&&(i_wb_we)&&(!spi_busy);
		if ((i_wb_stb)&&(i_wb_we)&&(!spi_busy))
		begin
			if (i_wb_addr[6])
			begin
				// 16-bit read/write
				data_reg <= { !oe, auto_addr_increment,
					i_wb_addr[5:0], i_wb_data[15:0] };
				busy_reg <= { 25'h1_ff_ff_ff };
				done_pipe <= { 25'h0_00_00_01 };
				short <= 1'b0;
			end else begin
				data_reg <= { !oe, auto_addr_increment,
					i_wb_addr[5:0], i_wb_data[7:0], 8'hf };
				busy_reg <= { 25'h1_ff_ff_00 };
				done_pipe <= { 25'h0_00_01_00 };
				short <= 1'b1;
			end
			o_mems_cs_n <= 1'b0;
			o_mems_sck  <= 1'b1;
			o_mems_mosi <= !i_wb_we;
		end else if (spi_ztimer && !spi_request)
		begin
			if (o_mems_sck)
			begin
				data_reg  <= { data_reg[ 22:0], 1'b0 };
				busy_reg  <= { busy_reg[ 23:0], 1'b0 };
			end

			if ((o_mems_sck)&&(busy_reg[23]))
			begin
				o_mems_sck <= 1'b0;
				o_mems_mosi <= data_reg[23];
				done_pipe <= { done_pipe[23:0], 1'b0 };
			end else if (o_mems_sck)
			begin
				o_mems_cs_n <= 1'b1;
				done_pipe <= 0;
			end

			if (!o_mems_sck)
				o_mems_sck <= 1'b1;
		end
	end
`ifdef	FORMAL
	always @(*)
		if (!busy_reg[24])
			assert((o_mems_sck)&&(o_mems_cs_n));
`endif

	initial	read_data = 16'h0;
	always @(posedge i_clk)
	if ((spi_ztimer)&&(!o_mems_sck))
		read_data <= { read_data[14:0], i_mems_miso };

	assign	done = (!i_reset)&&(spi_ztimer)&&(o_mems_sck)&&(!o_mems_cs_n)&&(done_pipe[24]);

	initial	o_done = 1'b0;
	always @(posedge i_clk)
		o_done <= done;

	initial	wb_return = 0;
	always @(posedge i_clk)
	if (done)
	begin
		if (short)
			wb_return <= {8'h0, read_data[7:0] };
		else if (OPT_SWAP_ENDIAN)
			wb_return <= { read_data[7:0], read_data[15:8] };
		else
			wb_return <= read_data[15:0];
	end
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

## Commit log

2018-03-13 Fleshed out the project with the full CPU support
    Project now builds
    - flash and SDRAM have not (yet) been integrated
    Still some bugs in hexbus that I was not expecting
    zipdbg on an initial (not loaded) CPU fails
    Work in progress
    [dualflexpress.v]
2019-02-22 Flash access supported, still need driver
2019-02-22 Added 3D case files to the repository
    [GT.scad, arrowzip.scad, arrowzip.stl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]
2019-03-06 Updated the README with the current project state
2019-04-01 New interrupt controller multi-LED demo
2019-04-02 Initial accelerometer support
2019-04-02 Draft accelerometer demo, lvldemo in sw/board
2019-04-03 Response to issue #11: declare before use
    [dualflexpress.v]

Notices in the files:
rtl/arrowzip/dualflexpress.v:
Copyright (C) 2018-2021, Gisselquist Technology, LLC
